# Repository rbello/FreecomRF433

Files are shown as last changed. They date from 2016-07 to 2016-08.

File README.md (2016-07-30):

# Arduino NANO + 433Mhz WL RF Emitter/Receiver

A small physical tool that displays the radio messages sent by home automation components using RF 433Mhz.

### Electronic diagram:

Using a 433Mhz WL RF Arduino/ARM/MCU ASK (B00G23NW6S) module.

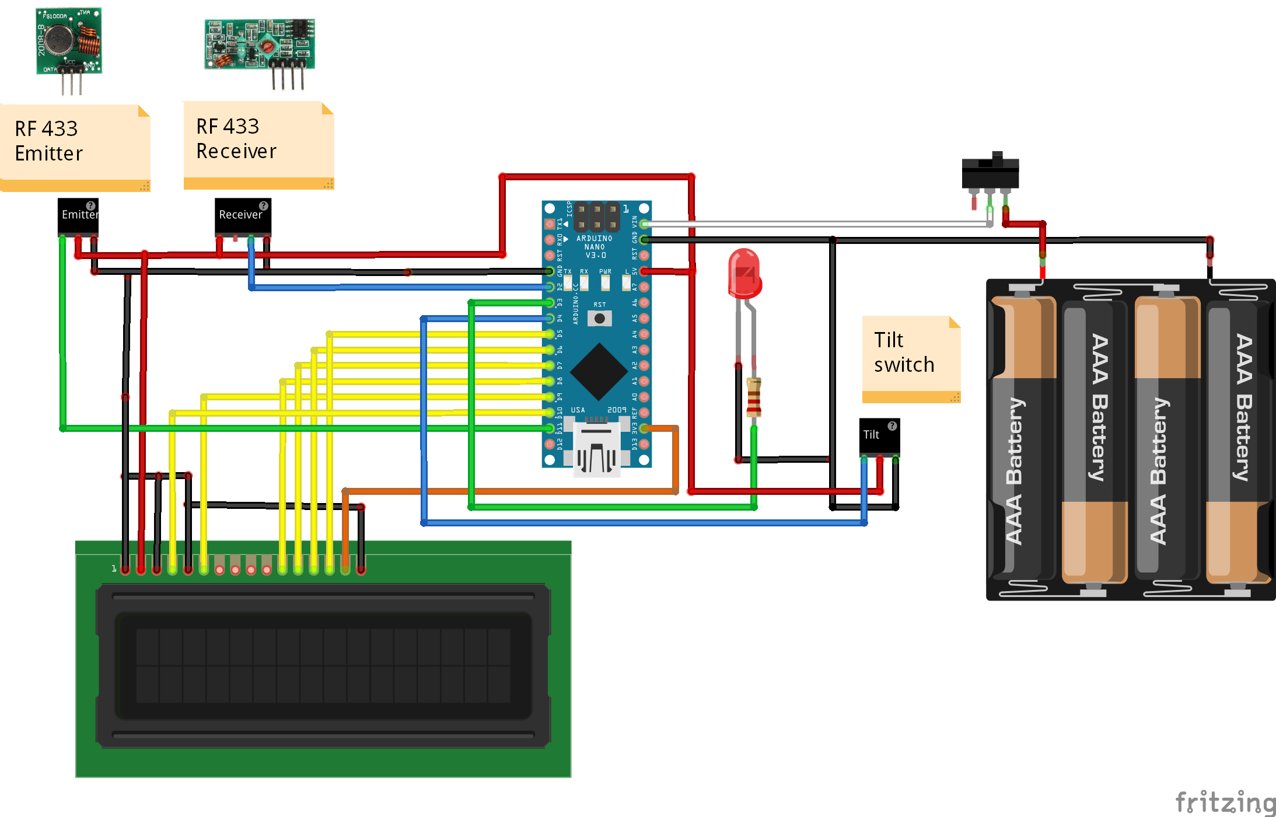
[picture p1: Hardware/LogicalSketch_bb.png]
Sketch


All the components are assembled:

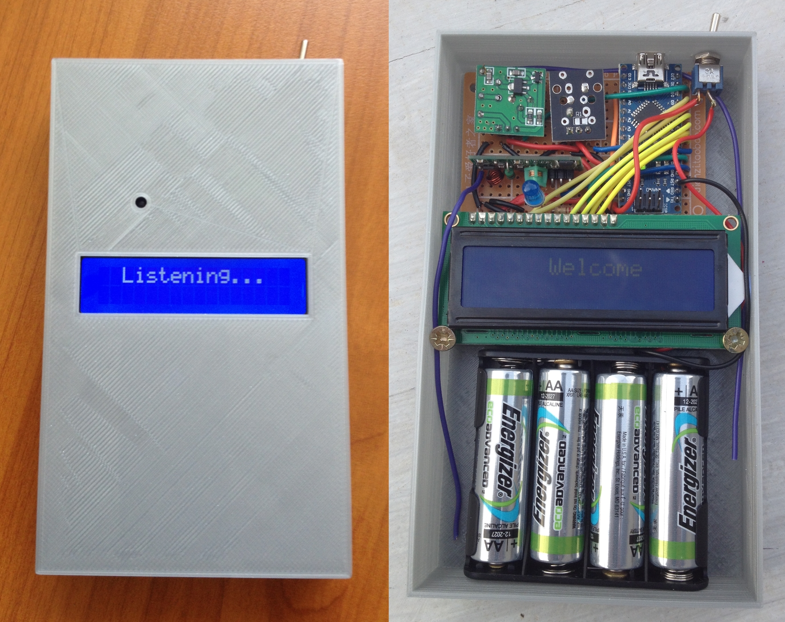
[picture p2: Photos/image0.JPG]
InternalElectronicPhoto


### Case conception

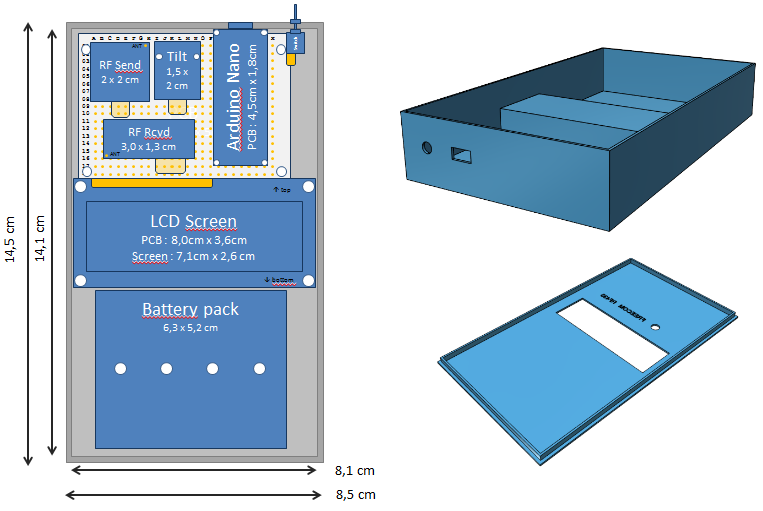
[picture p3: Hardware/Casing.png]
Casing


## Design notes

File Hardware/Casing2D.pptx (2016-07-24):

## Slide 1

Projet FreecomRF433 – 07/2016 – R. BELLO <github.com/rbello> - Creative commons by-nd
Internal view (top)

PCB
PCB : 7cm x 5cm

A B C D E F G H I J K L M N O P Q R S T U V W X

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
Arduino Nano
PCB : 4,5cm x 1,8cm

LCD Screen
PCB : 8,0cm x 3,6cm
Screen : 7,1cm x 2,6 cm

top

bottom

Battery pack
6,3 x 5,2 cm

Switch

RF Send
2 x 2 cm

ANT

RF Rcvd
3,0 x 1,3 cm

ANT

Tilt
1,5 x
2 cm

Case border:
0,2cm

14,1 cm

14,5 cm

8,1 cm

8,5 cm

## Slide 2

Projet FreecomRF433 – 07/2016 – R. BELLO <github.com/rbello> - Creative commons by-nd
Layered view (side)

LCD

LCD

Battery pack

USB

LCD

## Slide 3

Projet FreecomRF433 – 07/2016 – R. BELLO <github.com/rbello> - Creative commons by-nd
PCB welding and wiring

Connected holes by welding
(components face)

PCB
PCB : 7cm x 5cm

A B C D E F G H I J K L M N O P Q R S T U V W X

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
Welded pins
(components face)

PCB
PCB : 7cm x 5cm

A B C D E F G H I J K L M N O P Q R S T U V W X

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
LCD Screen

RF Emitter

RFSensor

Tilt

Nano

PCB
PCB : 7cm x 5cm

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
Connected holes by wires (under)

To battery
pack (GND)

To battery
pack (VCC)

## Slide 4

Projet FreecomRF433 – 07/2016 – R. BELLO <github.com/rbello> - Creative commons by-nd
Components view

Arduino Nano
PCB : 4,5cm x 1,8cm

Tilt
1,5 x
2 cm

RF Send
2 x 2 cm

ANT

RF Rcvd
3,0 x 1,3 cm

ANT

LCD Screen
PCB : 8,0cm x 3,6cm
Screen : 7,1cm x 2,6 cm

top

bottom

Battery pack
6,3 x 5,2 cm

Switch

PCB
PCB : 7cm x 5cm

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
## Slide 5

PCB
PCB : 7cm x 5cm

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
PCB : 7cm x 5cm

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
PCB : 7cm x 5cm

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
PCB : 7cm x 5cm

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
PCB : 7cm x 5cm

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
PCB : 7cm x 5cm

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
PCB : 7cm x 5cm

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
PCB : 7cm x 5cm

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
PCB : 7cm x 5cm

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
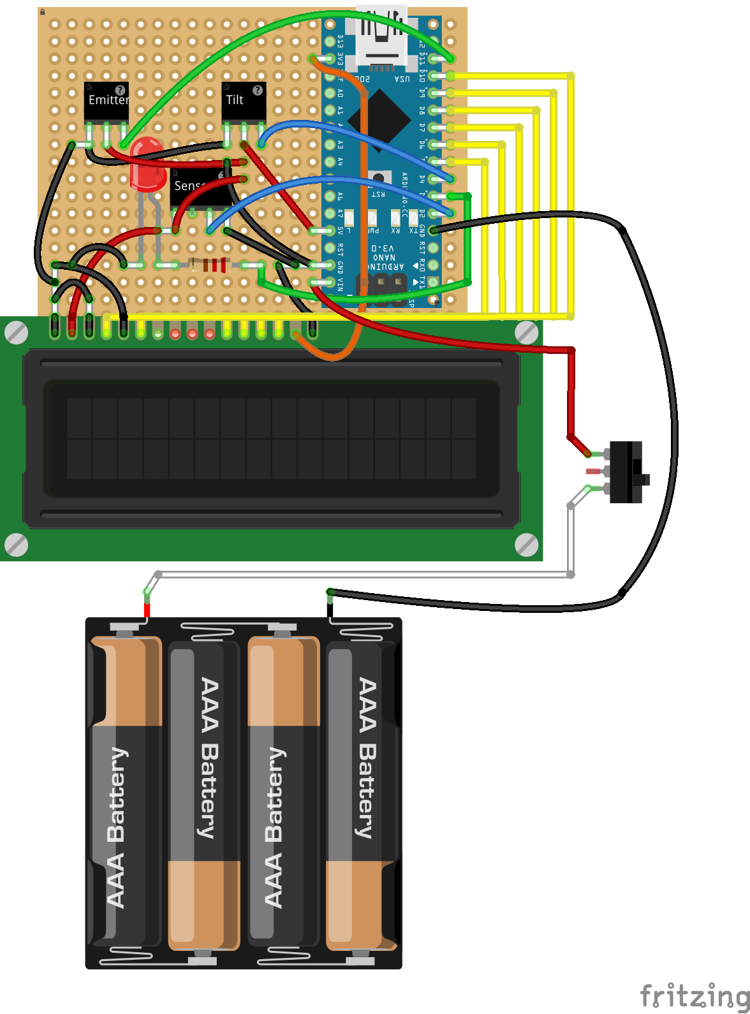
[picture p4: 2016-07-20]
Hardware/PhysicalSketch_bb.png

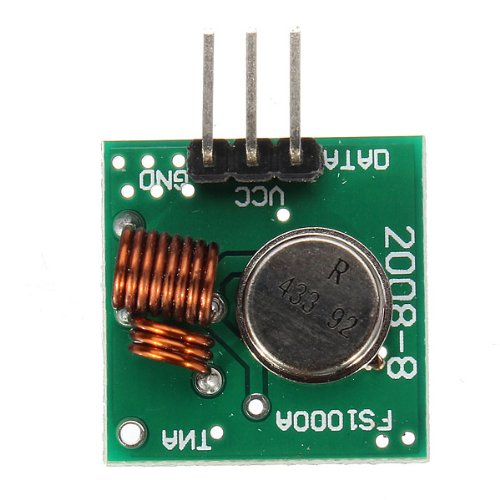
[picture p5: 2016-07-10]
Hardware/Transmitter.jpg

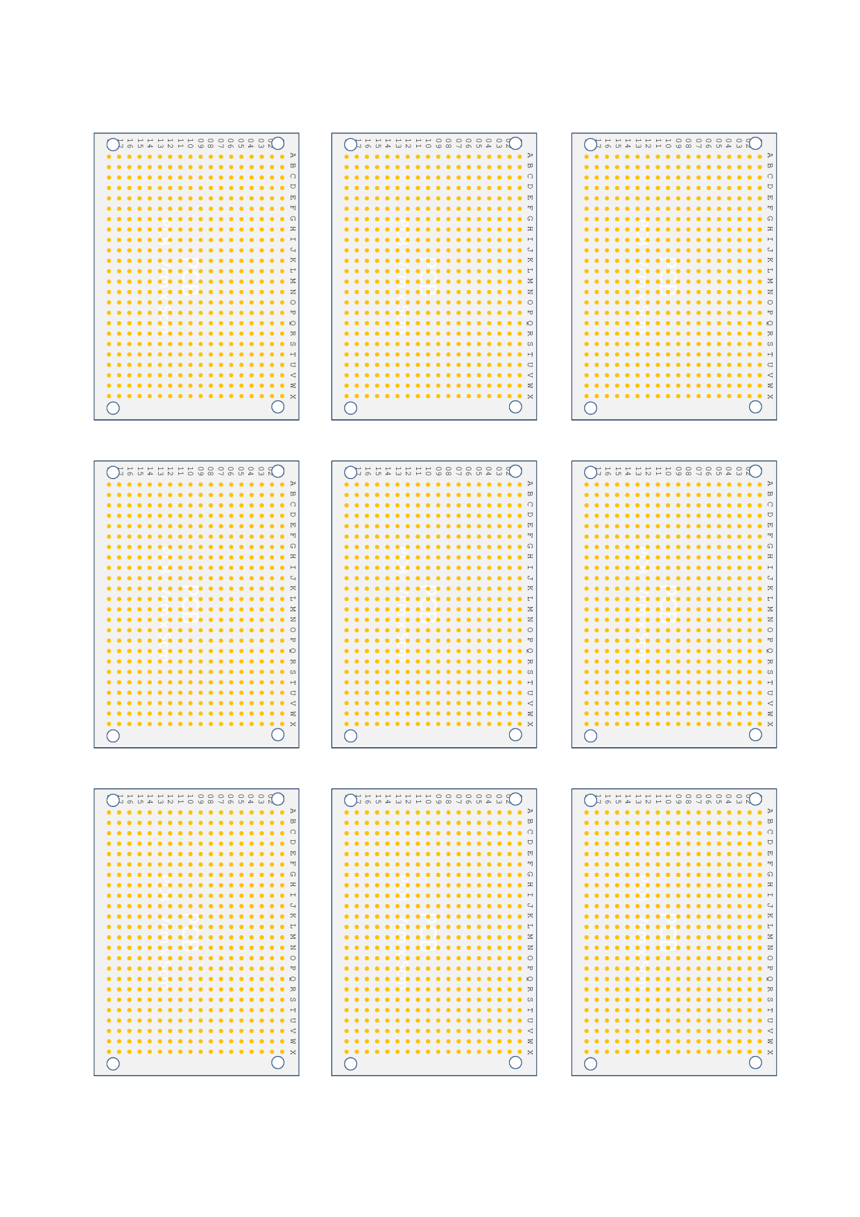
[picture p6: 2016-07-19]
Hardware/EmptyPCB.png

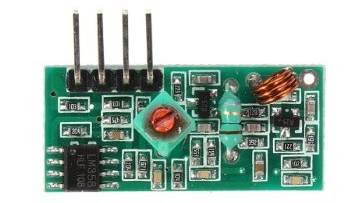
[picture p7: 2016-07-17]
Hardware/Receiver.jpg

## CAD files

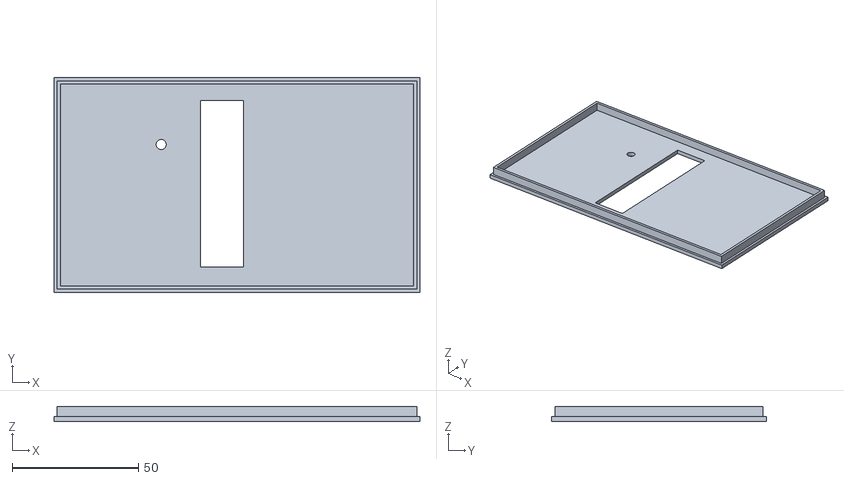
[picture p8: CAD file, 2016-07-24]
Hardware/Casing3D_top.stl
145.0 x 85.0 x 6.00

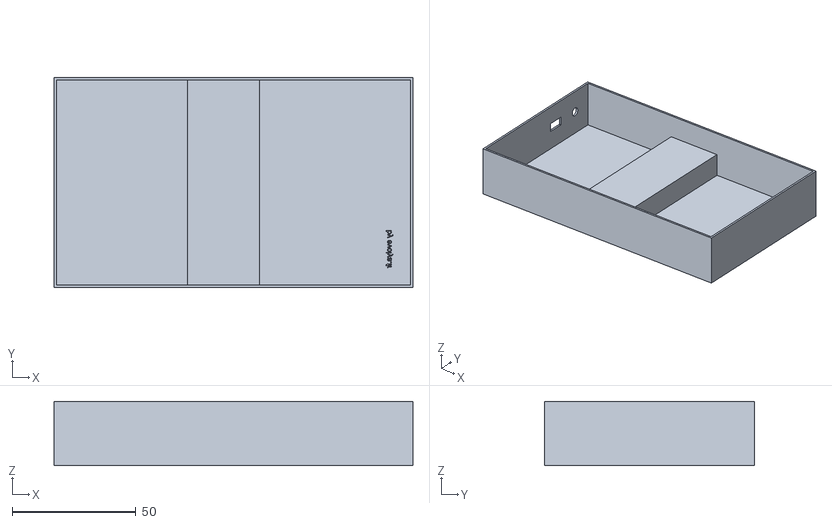
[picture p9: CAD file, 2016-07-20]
Hardware/Casing3D_bottom.stl
145.0 x 85.0 x 26.0

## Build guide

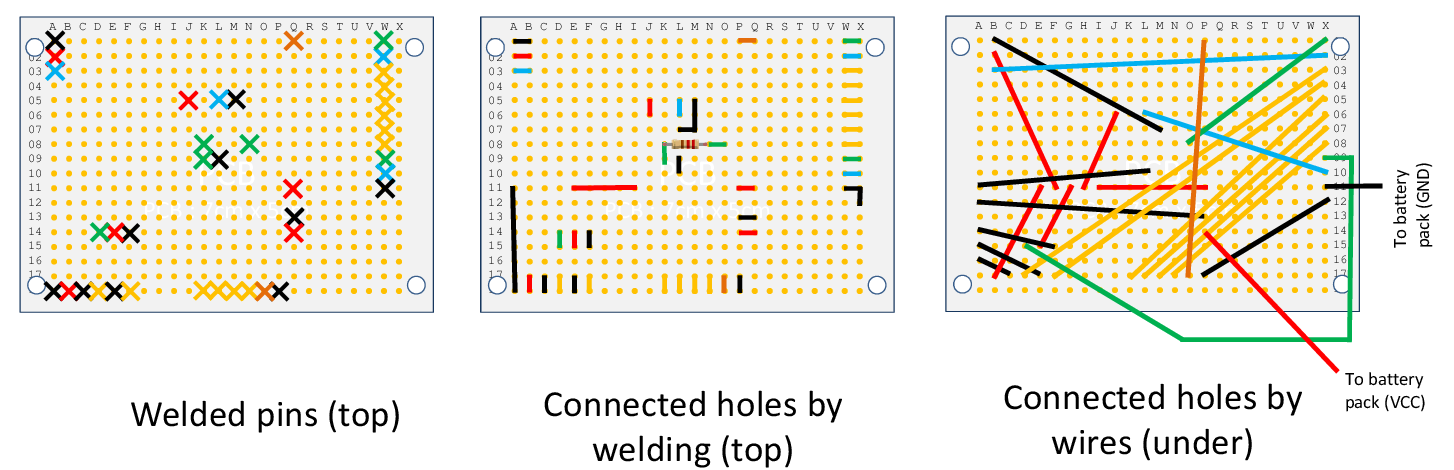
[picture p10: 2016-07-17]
Hardware/PcbWeldingWiring.png

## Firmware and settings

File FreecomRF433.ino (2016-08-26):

//============================================================================
// Name        : FreecomRF43.ino
// Author      : R. BELLO <https://github.com/rbello>
// Version     : 1.1
// Copyright   : Creative Commons (by)
// Description : A small physical tool that displays the radio messages sent by home automation components using RF 433Mhz.
//============================================================================

#include <LiquidCrystal.h>
#include <RCSwitch.h>

#define INT_433_SENSOR  0     // Interruption pin for RF 433 sensor (#2)
#define PIN_433_EMITTER 11    // Pin for RF 433 emitter
#define PIN_LCD_RS 10         // Pin for LCD display
#define PIN_LCD_E  9          // Pin for LCD display
#define PIN_LCD_D4 8          // Pin for LCD display
#define PIN_LCD_D5 7          // Pin for LCD display
#define PIN_LCD_D6 6          // Pin for LCD display
#define PIN_LCD_D7 5          // Pin for LCD display
#define PIN_TILT 4            // Pin for tilt switch
#define PIN_LED  3            // Pin for external LED

// LCD display
LiquidCrystal lcd(PIN_LCD_RS, PIN_LCD_E, PIN_LCD_D4, PIN_LCD_D5, PIN_LCD_D6, PIN_LCD_D7);

// Sensors RF 433Mhz
RCSwitch rf433read = RCSwitch();
RCSwitch rf433write = RCSwitch();

void setup() {

  // Status LED
  pinMode(PIN_LED, OUTPUT);

  // Tilt switch
  pinMode(PIN_TILT, INPUT);

  // Init serial
  Serial.begin(9600);

  // Init RF 433
  rf433read.enableReceive(INT_433_SENSOR);
  rf433read.setPulseLength(321);
  rf433write.enableTransmit(PIN_433_EMITTER);
  rf433write.setPulseLength(320);
  rf433write.setProtocol(2);

  // Init LCD display
  lcd.begin(16, 2);

  // Display welcome message
  lcd.clear();
  lcd.setCursor(0, 0);
  lcd.print("  Listening...");
  digitalWrite(PIN_LED, HIGH);
  delay(100);
  digitalWrite(PIN_LED, LOW);
  delay(100);
  digitalWrite(PIN_LED, HIGH);
  delay(100);
  digitalWrite(PIN_LED, LOW);
  delay(100);
  digitalWrite(PIN_LED, HIGH);
  delay(100);
  digitalWrite(PIN_LED, LOW);
  Serial.println("Ready");

}

void sendRf(long data) {
  // LED on
  digitalWrite(PIN_LED, HIGH);
  // Log
  Serial.print("Rf433Mhz: sent ");
  Serial.println(data);
  // LCD display
  lcd.clear();
  lcd.setCursor(0, 0);
  lcd.print("Sending...");
  lcd.setCursor(0, 1);
  char buf[50];
  sprintf(buf, "%lu", data);
  lcd.print(buf);
  // Rf433 send
  rf433write.send(data, 32);
  rf433write.send(data, 32);
  // LED off
  digitalWrite(PIN_LED, LOW);
}

int tilt_hits = 0;
unsigned long tilt_time = 0;
bool tilt_state = false;

long last_value = 0;
unsigned int last_protocol = 0;
unsigned long last_update = 0;
bool last_changed = false;

void loop() {

    // Tilt switch
    if (digitalRead(PIN_TILT) == HIGH) {
      if (!tilt_state) {
        tilt_state = true;
        tilt_hits++;
      }
    }
    else {
      tilt_state = false;
    }
    if (millis() - tilt_time > 400) {
        tilt_time = millis();
        if (tilt_hits >= 3) {
          //Serial.println("Tilt: hit");
          last_value = 0;
          last_changed = false;
          lcd.clear();
          lcd.setCursor(0, 0);
          lcd.print("  Listening...");
        }
        tilt_hits = 0;
    }

    // RF 433 receiver
    if (rf433read.available())
    {
      unsigned long value = rf433read.getReceivedValue();
      if (value == 0)
      {
        Serial.println("Rf433Mhz: rcvd error");
      }
      else {
        // LED on
        digitalWrite(PIN_LED, HIGH);
        // Log
        Serial.print("Rf433Mhz: rcvd ");
        char buf[50];
        sprintf(buf, "%lu", value);
        Serial.println(buf);
        // Save value
        last_value = value;
        last_protocol = rf433read.getReceivedProtocol();
        last_update = millis();
        last_changed = true;
        // LED off
        digitalWrite(PIN_LED, LOW);
      }
      rf433read.resetAvailable();
    }

    // Display value
    if (last_value > 0) {
        unsigned long t = (millis() - last_update) / 1000;
        if (t > 999) {
          lcd.clear();
          lcd.setCursor(0, 0);
          lcd.print("  Listening...");
          last_value = 0;
        }
        else {
          if (last_changed) {
            //Serial.println("Changed");
            lcd.clear();
            last_changed = false;
          }
          lcd.setCursor(0, 0);
          char buf2[50];
          sprintf(buf2, "Rcvd: P=%d T=%d", last_protocol, t);
          lcd.print(buf2);
          lcd.setCursor(0, 1);
          char buf[50];
          sprintf(buf, "%lu", last_value);
          lcd.print(buf);
        }
    }

    // Handle inputs from serial
    if (Serial.available() > 0)
    {
      long data = String(Serial.readString()).toInt();
      if (data > 0)
      {
        sendRf(data);
      }
    }
}

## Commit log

2016-07-17 Casing with 3d printer
    [Sketch.fzz]
2016-07-17 Fix conception (Add 3,3v connection to lcd screen)
    [Sketch.fzz]
2016-07-19 Casing2D + change configuration
    [LogicalSketch.fzz, PhysicalSketch.fzz, Sketch.fzz]
2016-07-20 Modelisation 3D v1
    [Casing3D_bottom.stl, Casing3D_top.stl, PhysicalSketch.fzz]
2016-07-21 Code improvement + case fix
    [Casing3D_top2.stl]
2016-07-24 Model 3D + doc
    [Casing3D_top.stl, Casing3D_top2.stl]
2016-08-26 Fix clear display bug
    [FreecomRF433.ino]
